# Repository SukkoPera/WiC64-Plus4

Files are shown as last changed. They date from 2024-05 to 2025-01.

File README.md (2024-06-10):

# WiC+4
WiC+4 is a wireless interface based on the ESP32 chip for the Commodore +4.

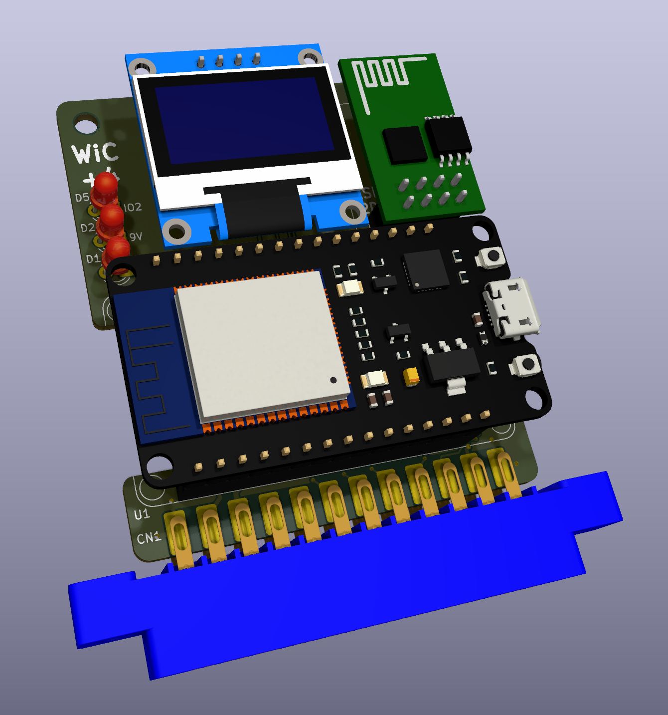
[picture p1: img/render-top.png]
Board


## Summary
This is just a customization of [the original WiC64 project](https://github.com/WiC64-Team/wic64-hardware) in order to make it work on the Commodore +4. In fact, while this computer features a User Port that looks very similar to the one you can find on the C64, the electrical connections are different and thus some modifications are required.

The board should also be usable on a C16 or C116 through [a User Port card](https://github.com/SukkoPera/16up).

Apart from the functional changes:
* I have added a jumper that selects whether the ESP should be powered by the rectified +9VAC or by the 5V rail.
* Consequently, I have added a ferrite on the 5V rail. An axial inductor should also fit, some experimentation will show what is better.
* I have switched the resistor footprints to 0805 for easier hand solderability.

The board keeps exactly the same size and major component layout, so all enclosures should still be usable.

## Usage
One of my goals was to make the modifications in a way such that **no changes would be required on the firmware side**.

Nevertheless, **this thing is completely unusable at the moment**, since no computer-side software exists.

What needs to be done is to take [this library](https://github.com/WiC64-Team/wic64-library) and adapt it so that:

* Data I/O takes place through the User Port
* The PC2 signal (ack/strobe: byte read from/written to port, rising edge) is controlled through /DTR
* The PA2 signal (Direction: HIGH = C64/+4 => ESP, LOW = ESP => C64/+4) is controlled through /RTS
* The FLAG2 signal (ack/strobe: byte read from/written to port, falling edge) can be read through /DCD.

/DTR and /RTS can be controlled through bits 0 and 3 (respectively) of $FD02 (Note that there is an inverter gate inbetween, so they are not really active-low).

/DCD can be read through bit 4 of $FD01 (again, mind the inverter gate). An interrupt can also be set up to track its changes if required.

I recommend taking a quick look at the 6551 ACIA datasheet in order to understand how to treat the other bits properly.

Another recommendation would be to make the User Port/ACIA base addresses configurable, for those who might want to use the 16UP board in External mode.

I had actually done part of the above work, only to find out that **I would then need a "launcher" program that is not open source, so I decided to stop all development**.

Please refer to [the original project](https://github.com/WiC64-Team/wic64-hardware) for all documentation, firmware, drivers, etc.

## Assembly
If you decide to use power from the 5V rail, the diode bridge and 220uF cap can be skipped.

The ESP-01 board in the top right corner is only required for debugging.

## Releases
If you want to get this board produced, you are recommended to get [the latest release](https://github.com/SukkoPera/WiC64-Plus4/releases) rather than the current git version, as the latter might be under development and is not guaranteed to be working.

Every release is accompanied by its Bill Of Materials (BOM) file and any relevant notes about it, which you are recommended to read carefully.

## License
WiC+4 is distributed under the [CC-BY 4.0 license](https://creativecommons.org/licenses/by/4.0/).

WiC+4 is provided to you ‘as is’ and without any express or implied warranties whatsoever with respect to its functionality, operability or use, including, without limitation, any implied warranties of merchantability, fitness for a particular purpose or infringement. We expressly disclaim any liability whatsoever for any direct, indirect, consequential, incidental or special damages, including, without limitation, lost revenues, lost profits, losses resulting from business interruption or loss of data, regardless of the form of action or legal theory under which the liability may be asserted, even if advised of the possibility or likelihood of such damages.

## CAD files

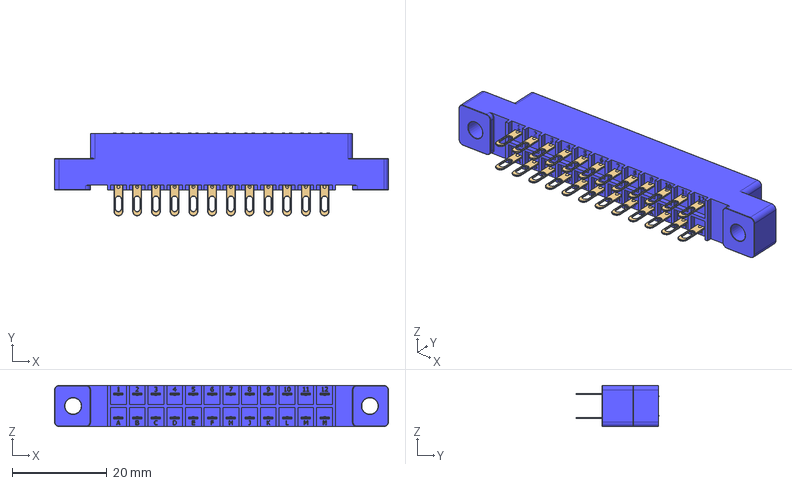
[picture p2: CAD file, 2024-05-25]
3dModels/C64 Userport Connector.STEP
70.6 x 17.5 x 8.71 mm
Card Edge Connector 2x12 (Userport)
Metallzunge x 24
Trenner Edge Conn x 2

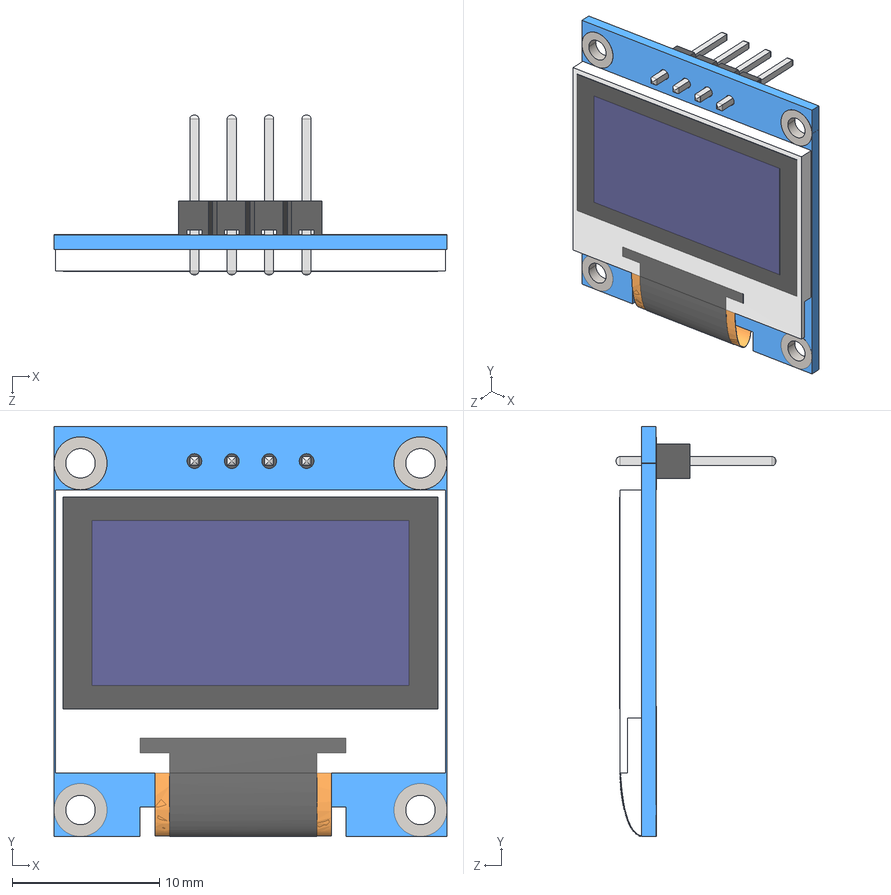
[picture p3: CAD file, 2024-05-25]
3dModels/128x64I2COLEDDisplayAdafruit.step
26.7 x 27.9 x 10.8 mm

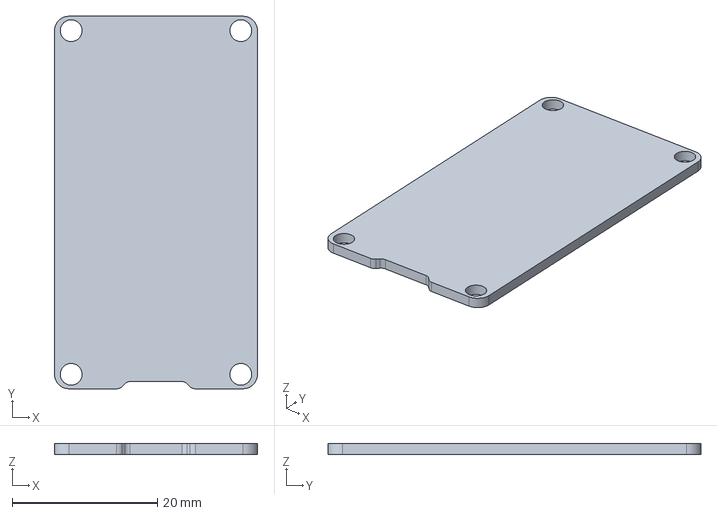
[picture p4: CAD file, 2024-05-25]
3dModels/esp32_devkit_v1_doit.step
28.0 x 51.4 x 1.50 mm

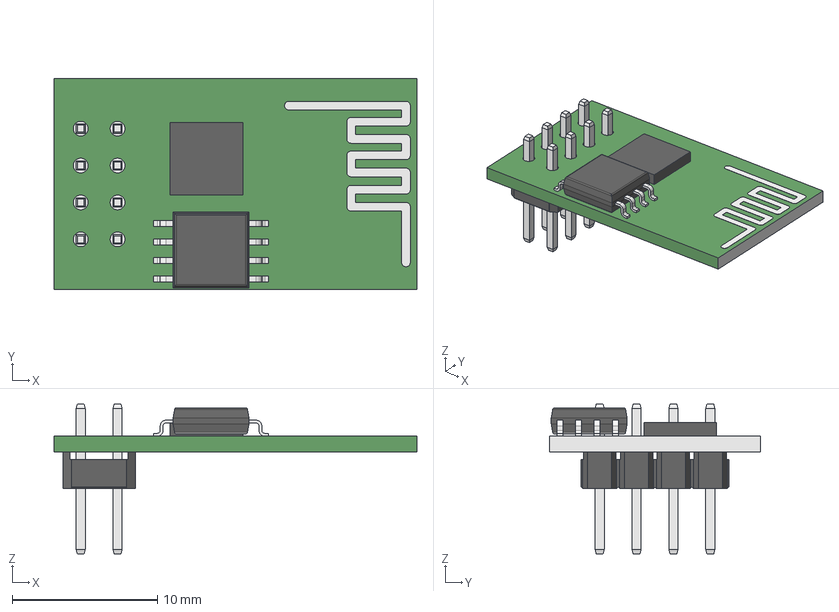
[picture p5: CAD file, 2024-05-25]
3dModels/ESP8266_ESP01_cp.step
25.0 x 14.5 x 10.3 mm

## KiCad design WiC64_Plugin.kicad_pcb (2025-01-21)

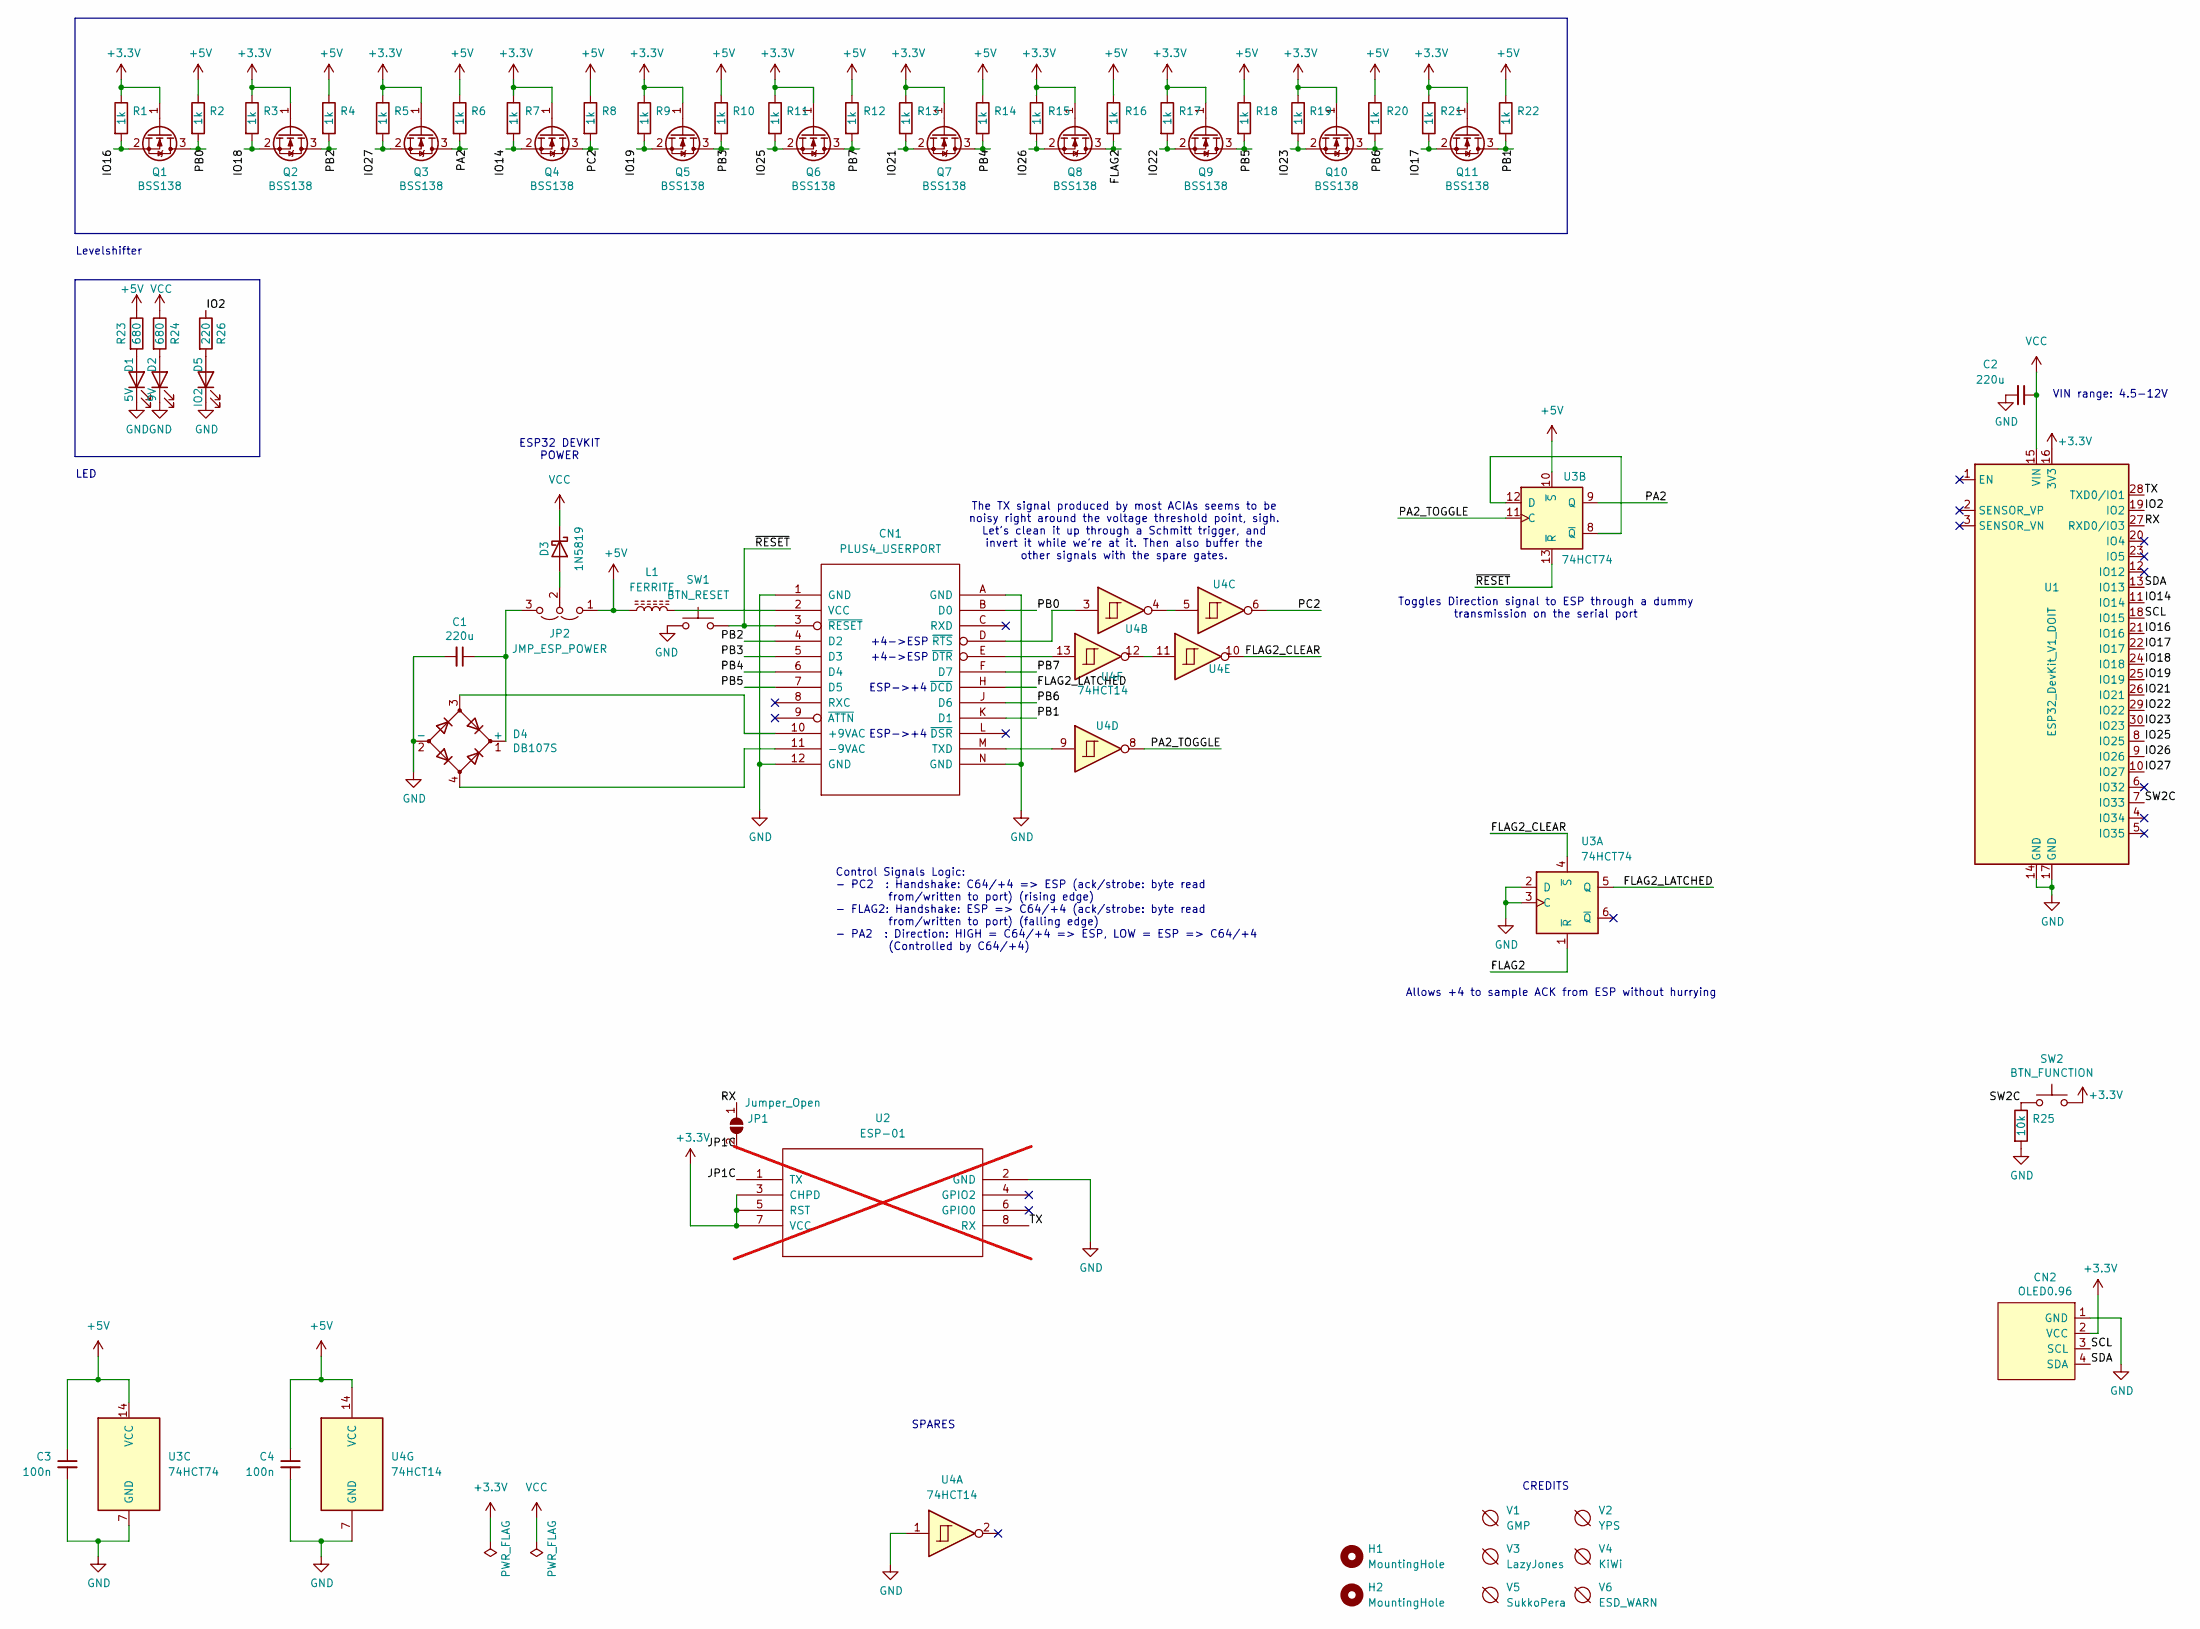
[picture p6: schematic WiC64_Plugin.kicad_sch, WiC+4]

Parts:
C1, C2: 220u; CP_6.3x11mm_horiz-R; LCSC (C269997)
C3, C4: 100n; C_0805_2012Metric_Pad1.18x1.45mm_HandSolder; LCSC C49678
CN1: PLUS4_USERPORT; UPS24CONN
CN2: OLED0.96; PinSocket_1x04_P2.54mm_Vertical; LCSC (C2718488)
D1: 5V; LED_D3.0mm; LCSC (C568936)
D2: 9V; LED_D3.0mm; LCSC (C568937)
D3: 1N5819; D_SMA; LCSC C8678
D4: DB107S; Diode_Bridge_Diotec_SO-DIL-Slim; LCSC C190797
D5: IO2; LED_D3.0mm; LCSC (C3310 5 6)
H1, H2: MountingHole; MountingHole_3.2mm_M3_ISO7380
JP1: Jumper_Open; SolderJumper-2_P1.3mm_Open_RoundedPad1.0x1.5mm
JP2: JMP_ESP_POWER; SolderJumper-3_P1.3mm_Open_RoundedPad1.0x1.5mm
L1: FERRITE; Ferrite_D6.0mm_L10.00mm_Horizontal
Q1, Q2, Q3, Q4, Q5, Q6, Q7, Q8, Q9, Q10, Q11: BSS138; SOT-23_Handsolder; LCSC C112239
R1, R2, R3, R4, R5, R6, R7, R8, R9, R10, R11, R12, R13, R14, R15, R16, R17, R18, R19, R20, R21, R22: 1k; R_0805_2012Metric_Pad1.20x1.40mm_HandSolder; LCSC C17513
R23, R24: 680; R_0805_2012Metric_Pad1.20x1.40mm_HandSolder; LCSC C17798
R25: 10k; R_0805_2012Metric_Pad1.20x1.40mm_HandSolder; LCSC C17414
R26: 220; R_0805_2012Metric_Pad1.20x1.40mm_HandSolder; LCSC C17557
SW1: BTN_RESET; SW_Tactile_SPST_Angled_PTS645Vx58-2LFS; LCSC (C406160)
SW2: BTN_FUNCTION; SW_Tactile_SPST_Angled_PTS645Vx58-2LFS; LCSC (C406160)
U1: ESP32_DevKit_V1_DOIT; esp32_devkit_v1_doit; LCSC (C7509525)
U2: ESP-01; LCSC (C2977588); not fitted
U3: 74HCT74; SOIC-14_3.9x8.7mm_P1.27mm; LCSC C39990
U4: 74HCT14; SOIC-14_3.9x8.7mm_P1.27mm; LCSC C609750
V1: GMP
V2: YPS; YPS2
V3: LazyJones; LazyJones2
V4: KiWi
V5: SukkoPera; PearLogo
V6: ESD_WARN; ESD-Logo_6.6x6mm_SilkScreen

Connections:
+3.3V: CN2.2 (VCC), Q1.1 (G), Q2.1 (G), Q3.1 (G), Q4.1 (G), Q5.1 (G), Q6.1 (G), Q7.1 (G), Q8.1 (G), Q9.1 (G), Q10.1 (G), Q11.1 (G), R1.1, R3.1, R5.1, R7.1, R9.1, R11.1, R13.1, R15.1, R17.1, R19.1, R21.1, SW2.2, U1.16 (3V3), U2.3 (CHPD), U2.5 (RST), U2.7 (VCC)
+5V: C3.1, C4.1, JP2.1 (A), L1.1, R2.1, R4.1, R6.1, R8.1, R10.1, R12.1, R14.1, R16.1, R18.1, R20.1, R22.1, R23.1, U3.10 (~S), U3.14 (VCC), U4.14 (VCC)
/FLAG2: Q8.3 (D), R16.2, U3.1 (~R)
/FLAG2_CLEAR: U3.4 (~S), U4.10
/FLAG2_LATCHED: CN1.H (~DCD), U3.5 (Q)
/IO2: R26.1, U1.19 (IO2)
/IO14: Q4.2 (S), R7.2, U1.11 (IO14)
/IO16: Q1.2 (S), R1.2, U1.21 (IO16)
/IO17: Q11.2 (S), R21.2, U1.22 (IO17)
/IO18: Q2.2 (S), R3.2, U1.24 (IO18)
/IO19: Q5.2 (S), R9.2, U1.25 (IO19)
/IO21: Q7.2 (S), R13.2, U1.26 (IO21)
/IO22: Q9.2 (S), R17.2, U1.29 (IO22)
/IO23: Q10.2 (S), R19.2, U1.30 (IO23)
/IO25: Q6.2 (S), R11.2, U1.8 (IO25)
/IO26: Q8.2 (S), R15.2, U1.9 (IO26)
/IO27: Q3.2 (S), R5.2, U1.10 (IO27)
/JP1C: JP1.2 (B), U2.1 (TX)
/PA2: Q3.3 (D), R6.2, U3.9 (Q)
/PA2_TOGGLE: U3.11 (C), U4.8
/PB0: CN1.B (D0), Q1.3 (D), R2.2
/PB1: CN1.K (D1), Q11.3 (D), R22.2
/PB2: CN1.4 (D2), Q2.3 (D), R4.2
/PB3: CN1.5 (D3), Q5.3 (D), R10.2
/PB4: CN1.6 (D4), Q7.3 (D), R14.2
/PB5: CN1.7 (D5), Q9.3 (D), R18.2
/PB6: CN1.J (D6), Q10.3 (D), R20.2
/PB7: CN1.F (D7), Q6.3 (D), R12.2
/PC2: Q4.3 (D), R8.2, U4.6
/RX: JP1.1 (A), U1.27 (RXD0/IO3)
/SCL: CN2.3 (SCL), U1.18 (IO15)
/SDA: CN2.4 (SDA), U1.13 (IO13)
/SW2C: R25.1, SW2.1, U1.7 (IO33)
/TX: U1.28 (TXD0/IO1), U2.8 (RX)
/~RESET: CN1.3 (~RESET), SW1.1, U3.13 (~R)
GND: C1.2, C2.2, C3.2, C4.2, CN1.1 (GND), CN1.12 (GND), CN1.A (GND), CN1.N (GND), CN2.1 (GND), D1.1 (K), D2.1 (K), D4.2 (-), D5.1 (K), R25.2, SW1.2, U1.14 (GND), U1.17 (GND), U2.2 (GND), U3.2 (D), U3.3 (C), U3.7 (GND), U4.1, U4.7 (GND)
unnamed: CN1.10 (+9VAC), D4.3
unnamed: CN1.11 (-9VAC), D4.4
unnamed: CN1.M (TXD), U4.9
unnamed: CN1.2 (VCC), L1.2
unnamed: CN1.E (~DTR), U4.13
unnamed: CN1.D (~RTS), U4.3
unnamed: D1.2 (A), R23.2
unnamed: D2.2 (A), R24.2
unnamed: D3.2 (A), JP2.2 (C)
unnamed: C1.1, D4.1 (+), JP2.3 (B)
unnamed: D5.2 (A), R26.2
unnamed: U3.8 (~Q), U3.12 (D)
unnamed: U4.4, U4.5
unnamed: U4.11, U4.12
VCC: C2.1, D3.1 (K), R24.1, U1.15 (VIN)

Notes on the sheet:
+4->ESP
ESP->+4
VIN range: 4.5-12V
SPARES
CREDITS
Levelshifter
Allows +4 to sample ACK from ESP without hurrying
Control Signals Logic: - PC2 : Handshake: C64/+4 => ESP (ack/strobe: byte read from/written to port) (rising edge) - FLAG2: Handshake: ESP => C64/+4 (ack/strobe: byte read from/written to port) (falling edge) - PA2 : Direction: HIGH = C64/+4 => ESP, LOW = ESP => C64/+4 (Controlled by C64/+4)
The TX signal produced by most ACIAs seems to be noisy right around the voltage threshold point, sigh. Let's clean it up through a Schmitt trigger, and invert it while we're at it. Then also buffer the other signals with the spare gates.
LED
Toggles Direction signal to ESP through a dummy transmission on the serial port
ESP32 DEVKIT POWER

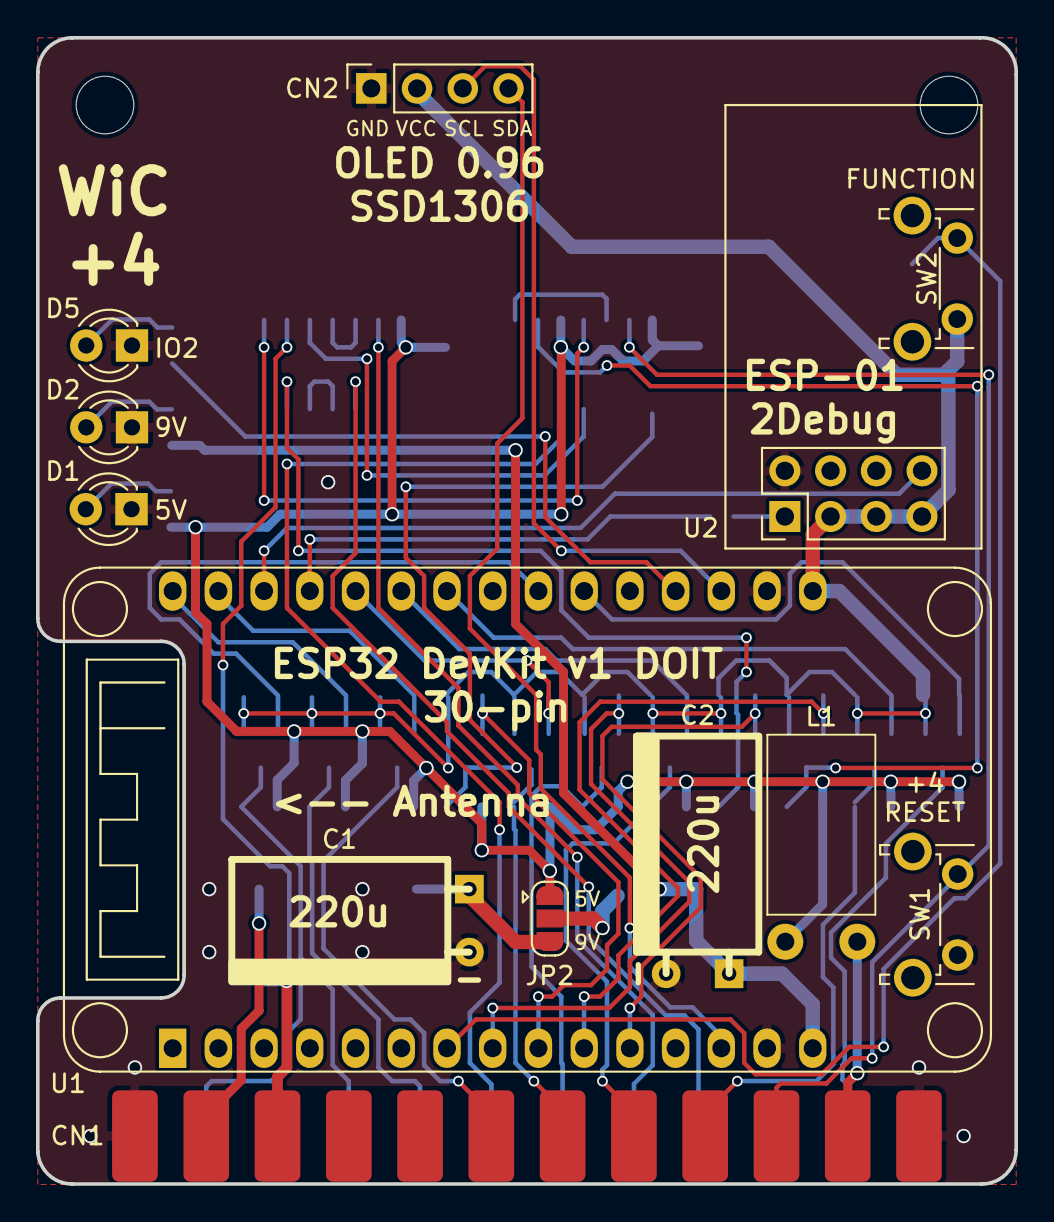
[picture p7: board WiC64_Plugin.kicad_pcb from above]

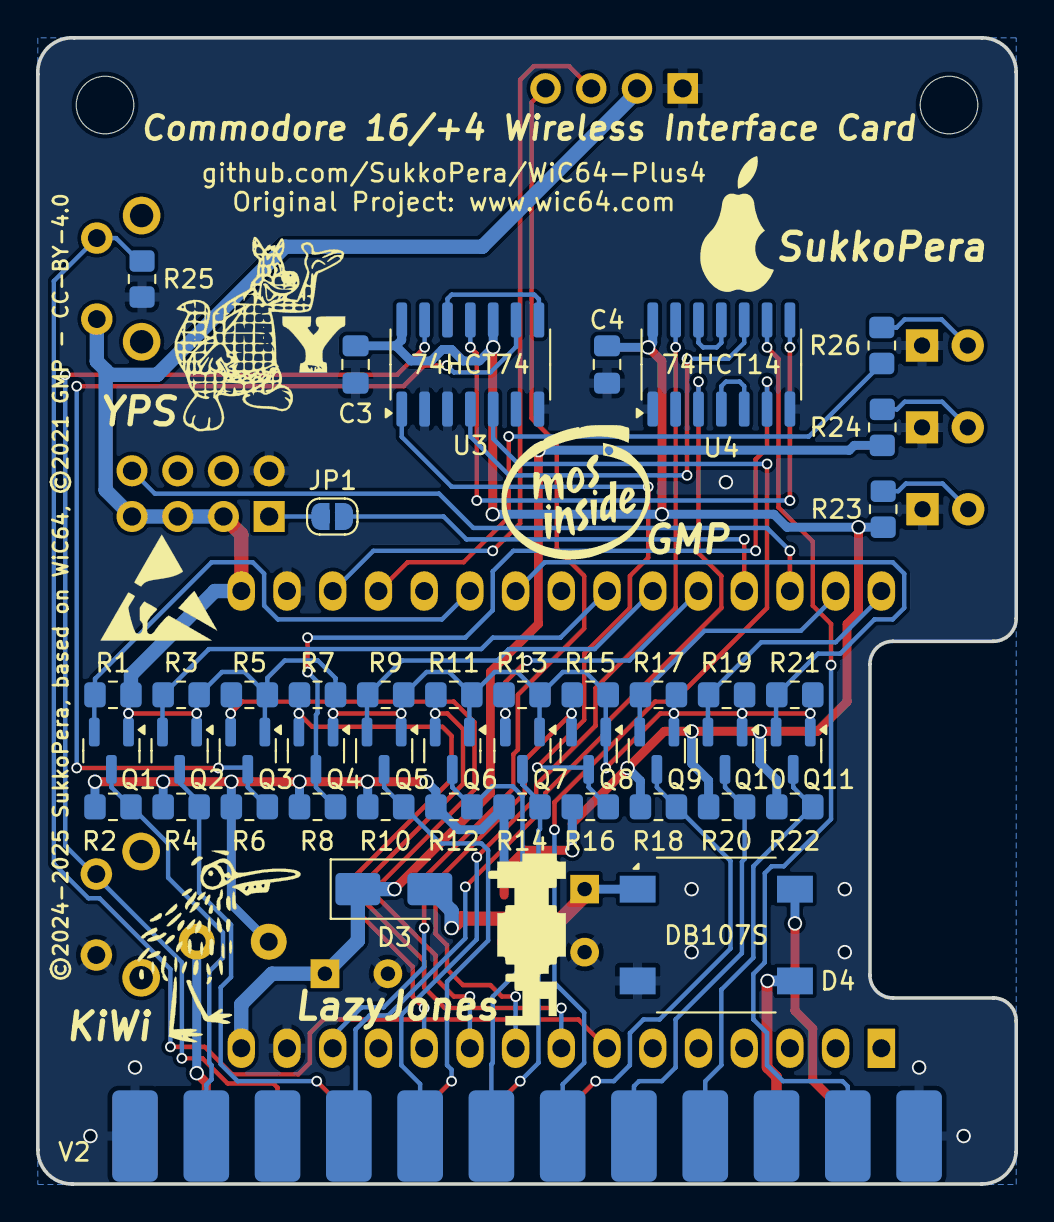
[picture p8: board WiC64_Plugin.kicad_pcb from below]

Board: 2 copper layers, 54.4 x 63.7 mm, 65 parts (50 on the bottom side), 51 nets.

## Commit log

2024-05-24 Fix board outline (and port to KiCad 8)
    [WiC64_Plugin.kicad_pcb]
2024-05-24 Find/Reconstruct missing libs/footprints and fix most DRC problems PCB is mostly untouched so far, focus was just on "completing" the released source files
    [WiC64_Plugin.kicad_pcb, WiC64_Plugin.kicad_sch]
2024-05-25 Move all files to root directory
    [WiC64_Plugin-B.Cu.gbl, WiC64_Plugin-B.Mask.gbs, WiC64_Plugin-B.Paste.gbp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]
2024-05-25 Make all resistors 0805
    [WiC64_Plugin.kicad_pcb, WiC64_Plugin.kicad_sch]
2024-05-25 Add 3D models
    [128x64I2COLEDDisplayAdafruit.step, C64 Userport Connector.STEP, ESP8266_ESP01_cp.step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]
2024-05-26 Remove redundant symbols
    [WiC64_Plugin.kicad_pcb, WiC64_Plugin.kicad_sch]
2024-05-26 Allow powering ESP32 from 5V
    [WiC64_Plugin.kicad_pcb, WiC64_Plugin.kicad_sch]
2024-05-26 Update gerber path
    [WiC64_Plugin.kicad_pcb]
2024-05-26 Move all footprints to single library
    [WiC64_Plugin.kicad_pcb, WiC64_Plugin.kicad_sch]
2024-05-28 Initial +4 version
    [WiC64_Plugin.kicad_pcb, WiC64_Plugin.kicad_sch]
2024-06-02 Complete changes for +4 version
    [WiC64_Plugin.kicad_pcb, WiC64_Plugin.kicad_sch]
2024-06-14 Move SCL/SDA tracks around
    [WiC64_Plugin.kicad_pcb]
2024-06-23 Latch FLAG2
    [WiC64_Plugin.kicad_pcb, WiC64_Plugin.kicad_sch]
2024-06-23 Final touches for V1FF
    [WiC64_Plugin.kicad_pcb, WiC64_Plugin.kicad_sch]
2024-09-09 Add Schmitt trigger to clean TX signal
    [WiC64_Plugin.kicad_pcb, WiC64_Plugin.kicad_sch]
2025-01-21 Various refinements for V1FFF
    [WiC64_Plugin.kicad_pcb, WiC64_Plugin.kicad_sch]
2025-01-21 Final-final-final touches
    [WiC64_Plugin.kicad_pcb]

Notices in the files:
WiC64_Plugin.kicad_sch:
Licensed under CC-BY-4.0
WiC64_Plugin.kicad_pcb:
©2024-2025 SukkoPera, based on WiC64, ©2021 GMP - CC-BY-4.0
